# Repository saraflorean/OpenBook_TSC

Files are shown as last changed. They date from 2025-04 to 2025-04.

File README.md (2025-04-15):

# OpenBook_TSC

## Florean Sara-Denisa - 333CD

# Diagrama Block

Diagrama Block

---

# Descrierea modulelor hardware

## Microcontroler – ESP32-C6-WROOM-1-N8

ESP32-C6 este unitatea centrală de procesare responsabilă pentru gestionarea tuturor operațiunilor sistemului, comunicarea cu senzorii și modulele, precum și managementul energiei.

- **Arhitectură:** RISC-V pe 32 de biți  
- **Frecvență ceas:** 160 MHz  
- **Conectivitate wireless:** Wi-Fi 6 la 2.4 GHz, Bluetooth 5.0  

## Management Energetic & Baterie

- **Tip baterie:** Li-Po (Litiu-Polimer)  
- **Capacitate:** 3.7V, 1800mAh  
- **Circuit de încărcare:** MCP73831T  
- **Tensiune de intrare:** 5V prin USB-C  
- **Protecții:** Protecție la supraîncărcare și descărcare profundă  
- **Regulator de tensiune:** Regulator LDO care asigură o alimentare stabilă de 3.3V pentru toate componentele
  
## Afișaj – Ecran E-Paper (E-Ink)

- **Dimensiune:** 7.5 inci  
- **Rezoluție:** 800x480 pixeli  
- **Interfață de comunicare:** SPI  

## Modul Card SD

- **Tip:** MicroSD (Suportă FAT32)  
- **Interfață:** SPI  

## Memorie NOR Flash Externă

- **Capacitate:** 64MB  
- **Interfață:** SPI  

## Senzor de Mediu – BME688

- **Funcții:** Măsoară temperatura, umiditatea, presiunea aerului și nivelurile de gaz  
- **Interfață de comunicare:** I2C  

## Ceas în Timp Real (RTC) – DS3231SN

- **Funcționalitate:** Păstrează ora și data chiar și atunci când sistemul este oprit  
- **Interfață de comunicare:** I2C  

## Conector USB-C & Protecție ESD

- **Funcționalitate:** Asigură alimentarea și transferul de date  
- **Protecție:** Protecție ESD integrată și diodă Schottky pentru protecție la polaritate inversă  

## Butoane & Interacțiune cu Utilizatorul

- **Butoane tactile (push):** Utilizate pentru control manual  

## Interfețe de Comunicație

- **GPIO:** Folosit pentru controlul butoanelor și operațiuni generale I/O  
- **SPI:** Utilizat pentru cardul SD, memoria flash externă și ecranul e-paper  
- **I2C:** Utilizat pentru senzorul de mediu BME688 și modulul RTC DS3231SN  
- **UART:** Utilizat pentru depanare și comunicație serială  
- **Wi-Fi & Bluetooth:** Asigurate de ESP32-C6 pentru conectivitate wireless  

---

## Lista Componentelor folosite

| Componentă | Link | Fișă Tehnică |
|---|---|---|
| MAX17048G+T10 | [Model](https://www.snapeda.com/parts/MAX17048G+T10/Analog+Devices/view-part/?ref=eda) | [Datasheet](https://www.alldatasheet.com/view.jsp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) |
| MCP73831T-5ACI/OT | [Model](https://www.mouser.co.uk/ProductDetail/Microchip-Technology/MCP73831T-5ACI-OT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) | [Datasheet](//efaidnbmnnnibpcajpcglclefindmkaj/https://ww1.microchip.com/downloads/en/DeviceDoc/MCP73831-Family-Data-Sheet-DS20001984H.pdf) |
| USB4110-GF-A  | [Model](https://componentsearchengine.com/part-view/USB4110-GF-A/GCT%20(GLOBAL%20CONNECTOR%20TECHNOLOGY)) | [Datasheet](//efaidnbmnnnibpcajpcglclefindmkaj/https://gct.co/files/drawings/usb4110.pdf) |
| Adafruit | [Model](https://eu.mouser.com/ProductDetail/Adafruit/4208?qs=PzGy0jfpSMtbScLbr0L5dw%3D%3D) | [Datasheet](https://www.arrow.com/en/manufacturers/adafruit-industries/datasheets) |
| CAPACITOR | [Model](https://componentsearchengine.com/part-view/R0402%201%25%20100%20K%20(RC0402FR-07100KL)/YAGEO) | [Datasheet](//efaidnbmnnnibpcajpcglclefindmkaj/https://www.resistor.com/assets/pdf/0402tstd.pdf) |
| CPH3225A | [Model](https://www.snapeda.com/parts/CPH3225A/Seiko+Instruments/view-part/?ref=eda) | [Datasheet](https://octopart.com/datasheet/cph3225a-seiko-25340571) |
| EVQPUJ02K | [Model](https://industry.panasonic.com/global/en/products/control/switch/light-touch/number/evqpuj02k) | [Datasheet](https://www.lcsc.com/datasheet/lcsc_datasheet_2201121800_PANASONIC-EVQPUJ02K_C2936858.pdf) |
| KP-1608SURCK | [Model](https://www.snapeda.com/parts/KP-1608SURCK/Kingbright/view-part/?ref=search&t=LED%200603) | [Datasheet](//efaidnbmnnnibpcajpcglclefindmkaj/https://media.elv.com/file/107153_led_surck1608_data.pdf) |
| USBLC6-2SC6Y | [Model](https://www.snapeda.com/parts/USBLC6-2SC6Y/STMicroelectronics/view-part/?ref=eda) | [Datasheet](https://www.digikey.com/en/htmldatasheets/production/1375342/0/0/1/usblc6-2sc6y) |
| SD0805S020S1R0 | [Model](https://ro.mouser.com/ProductDetail/KYOCERA-AVX/SD0805S020S1R0?qs=jCA%252BPfw4LHbpkAoSnwrdjw%3D%3D) | [Datasheet](https://www.alldatasheet.com/view.jsp?Searchword=SD0805S&sField=2) |
| PGB1010603MR | [Model](https://www.snapeda.com/parts/PGB1010603MR/Littelfuse/view-part/?ref=eda) | [Datasheet](https://www.alldatasheet.com/view.jsp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) |
| BD5229G-TR  | [Model](https://componentsearchengine.com/part-view/BD5229G-TR/ROHM%20Semiconductor) | [Datasheet](https://www.lcsc.com/datasheet/lcsc_datasheet_2201131330_ROHM-Semicon-BD5229G-TR_C962636.pdf) |
| BME680 | [Model](https://www.snapeda.com/parts/BME680/Bosch/view-part/?welcome=home) | [Datasheet](//efaidnbmnnnibpcajpcglclefindmkaj/https://www.bosch-sensortec.com/media/boschsensortec/downloads/datasheets/bst-bme680-ds001.pdf) |
| XC6220A331MR-G | [Model](https://componentsearchengine.com/part-view/XC6220A331MR-G/Torex) | [Datasheet](https://www.alldatasheet.com/view.jsp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) |
| SMD Solder | [Model](https://grabcad.com/library/solder-jumpers-1) | [Datasheet]() |
| BUTTON | [Model](https://industry.panasonic.com/global/en/products/control/switch/light-touch/number/evqpuj02k) | [Datasheet](https://www.lcsc.com/datasheet/lcsc_datasheet_2201121800_PANASONIC-EVQPUJ02K_C2936858.pdf) |
| Bobina | [Model](https://store.comet.srl.ro/Catalogue/Product/43497/) | [Datasheet](https://www.scribd.com/document/814581278/Datasheet-Bobina) |
| PFMF | [Model](https://www.mouser.co.uk/ProductDetail/EPCOS-TDK/B72520T0350K062?qs=dEfas%2FXlABIszF52uu7vrg%3D%3D) | [Datasheet](https://ro.mouser.com/c/ds/circuit-protection/thermistors/resettable-fuses-pptc/?m=Schurter&series=PFMF) |
| DMG2305UX-7 | [Model](https://componentsearchengine.com/part-view/DMG2305UX-7/Diodes%20Incorporated) | [Datasheet](//efaidnbmnnnibpcajpcglclefindmkaj/https://www.mouser.com/datasheet/2/115/DMG2305UX-266242.pdf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) |
| Si1308EDL-T1-GE3 | [Model](https://componentsearchengine.com/part-view/SI1308EDL-T1-GE3/Vishay) | [Datasheet](https://www.alldatasheet.com/view.jsp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) |
| R0402 | [Model](https://componentsearchengine.com/part-view/R0402%201%25%20100%20K%20(RC0402FR-07100KL)/YAGEO) | [Datasheet](//efaidnbmnnnibpcajpcglclefindmkaj/https://www.resistor.com/assets/pdf/0402tstd.pdf) |
| W25Q512JVEIQ | [Model](https://www.snapeda.com/parts/ESP32-C6-WROOM-1-N8/Espressif+Systems/view-part/?ref=eda) | [Datasheet](//efaidnbmnnnibpcajpcglclefindmkaj/https://www.mouser.com/datasheet/2/949/W25Q512JV_SPI_RevB_06252019_KMS-2487502.pdf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) |
| ESP32-C6-WROOM-1-N8 | [Model](https://www.snapeda.com/parts/ESP32-C6-WROOM-1-N8/Espressif+Systems/view-part/?ref=eda) | [Datasheet](//efaidnbmnnnibpcajpcglclefindmkaj/https://www.mouser.com/catalog/specsheets/Espressif_ESP32_C6_WROOM_1%20_Datasheet_V0.1_PRELIMINARY_en.pdf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) |
| DS3231SN# | [Model](https://www.snapeda.com/parts/DS3231SN%23/Analog+Devices/view-part/?ref=eda) | [Datasheet](https://www.alldatasheet.com/view.jsp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) |

---

## Mapare Pini – ESP32-C6

| Denumire | Pin GPIO | Utilizare |
|---|---|---|
| Buton Reset | EN | Resetare ESP32-C6 |
| INT_RTC | IO0 | Semnal de întrerupere de la RTC (DS3231)|
| 32KHZ | IO1 | Semnal de ceas 32 kHz |
| MISO (SPI) | IO2 | Recepție date SPI |
| EPD BUSY | IO3 | Indicator stare E-Paper |
| SS_SD | IO4 | Chip Select pentru card SD (SPI) |
| EPD DC | IO5 | Data/Command pentru E-Paper |
| SCK (SPI) | IO6 | Clock pentru SPI |
| MOSI (SPI) | IO7 | Transmitere date SPI |
| Buton Boot | IO9 | Intrare în bootloader |
| 3V3 | 3V3 | Alimentare 3.3V |
| EPD_CS | IO10 | Selectare SPI pentru E-Paper |
| FLASH_CS | IO11 | Selectare SPI pentru NOR Flash |
| USB_D- | IO12 | Linie diferențială USB (minus) |
| USB_D+ | IO13 | Linie diferențială USB (plus) |
| Buton Change | IO15 | Schimbare mod operare |
| TX (UART) | TXD0/GPIO16 | Transmitere date UART |
| RX (UART) | RXD0/GPIO17 | Recepție date UART |
| RTC_RST | IO18 | Reset extern/semnal RTC |
| I2C_PW | IO19 | Linie de alimentare / enable pentru I2C |
| EPD_3V3_C | IO20 | Linie de alimentare 3.3V pentru E-Paper |
| SDA (I2C) | IO21 | Linie de date I2C |
| SCL (I2C) | IO22 | Linie de ceas I2C |
| EPD RST | IO23 | Resetare E-Paper |

---

## Informații adiționale

**Erori SMD-Hole Board Outline Clearance la Mufa USB:**  
  - Am identificat două erori de tip **SMD-Hole Board Outline Clearance** asociate mufei USB. Conform informațiilor tehnice primite, aceste erori au fost **acceptate**.

**Redimensionarea și amplasarea componentelor:**
  - Dimensiunile unor componente au fost **ajustate** pentru a rezolva incompatibilitățile detectate de verificatorul de design.
  - Condensatori de decuplare de 100nF au fost **amplasați aproape de pinii de alimentare** ai circuitelor integrate (IC), în conformitate cu practicile standard de proiectare pentru reducerea zgomotului electric.
  - Componentele au fost amplasate respectând pe cât de mult posibil **specifcațiile proiectului** asigurând compatibilitatea dintre carcasa oferită și dimensiunile PCB-ului.
  - **TP-urile** au fost amplasate diferit față de specificațiile oferite, pentru a facilita o rutare eficientă. Poziția lor fiind determinată de apropierea de piesele conectate.

 **Rutare și planuri de masă**
 - **Traseele de alimentare** au fost rutate **doar pe stratul superior**, ceea ce a necesitat utilizarea a aproximativ 100 de vias-uri pentru a permite rutarea semnalelor pe stratul inferior.
 - **Planul de masă** (GND) a fost adăugat după finalizarea rutării, aplicat atât pe stratul superior, cât și pe cel inferior, pentru a asigura o împământare cu impedanță redusă și pentru a diminua interferențele electromagnetice (EMI).
 - Am realizat **via stitching** în regiunile unde planurile de masă de pe stratul superior și inferior se suprapuneau, pentru a asigura o conexiune electrică solidă între acestea.

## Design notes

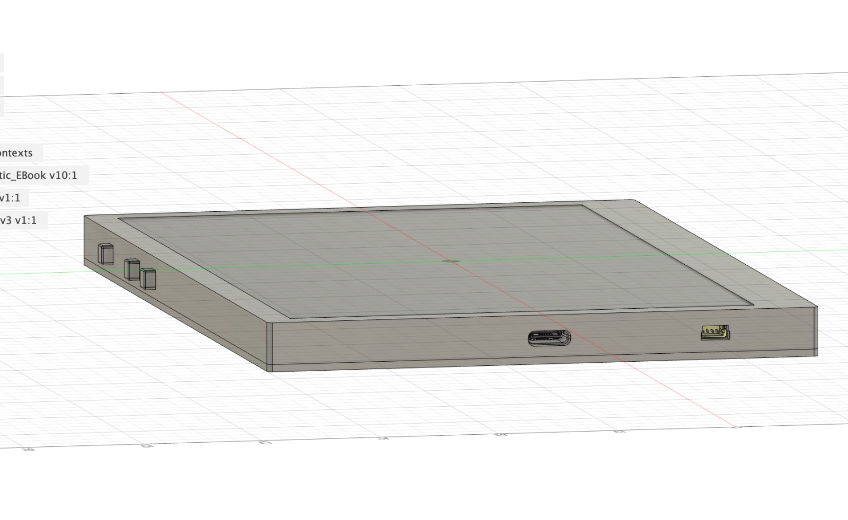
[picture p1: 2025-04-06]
Images/OpenBook.jpeg

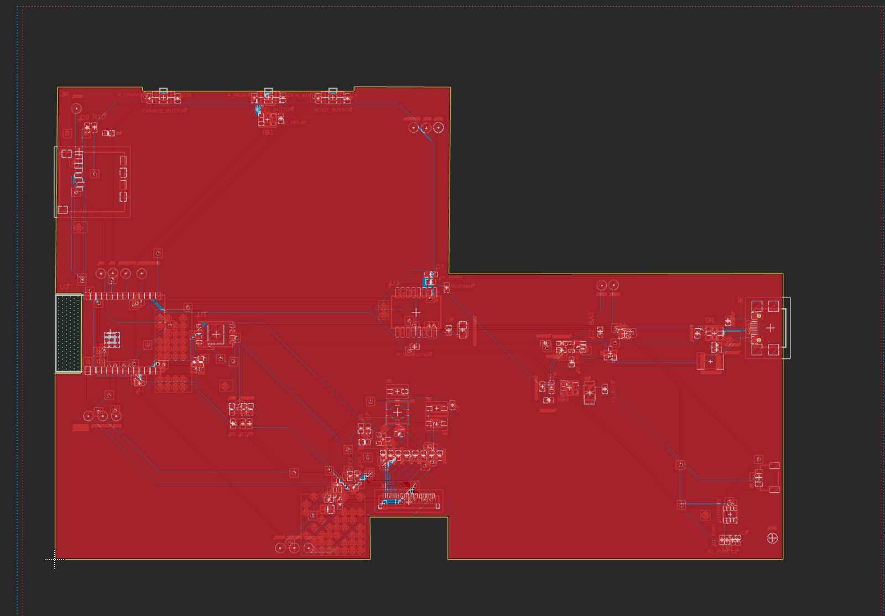
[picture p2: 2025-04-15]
Images/Top_Routing.jpeg

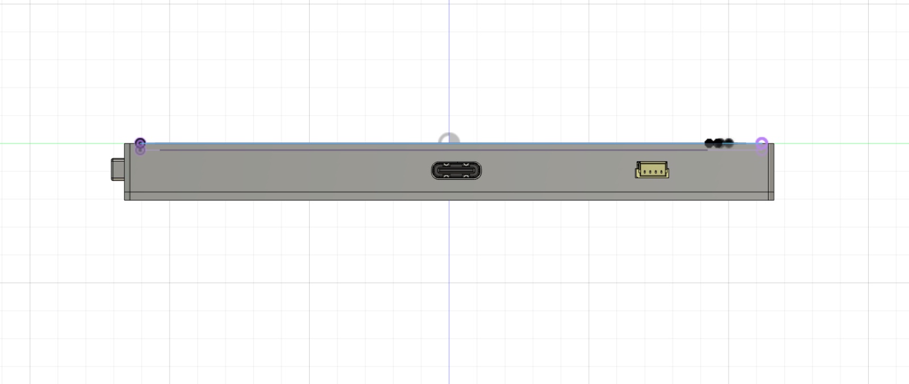
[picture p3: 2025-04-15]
Images/Extern_plug_ins.jpeg

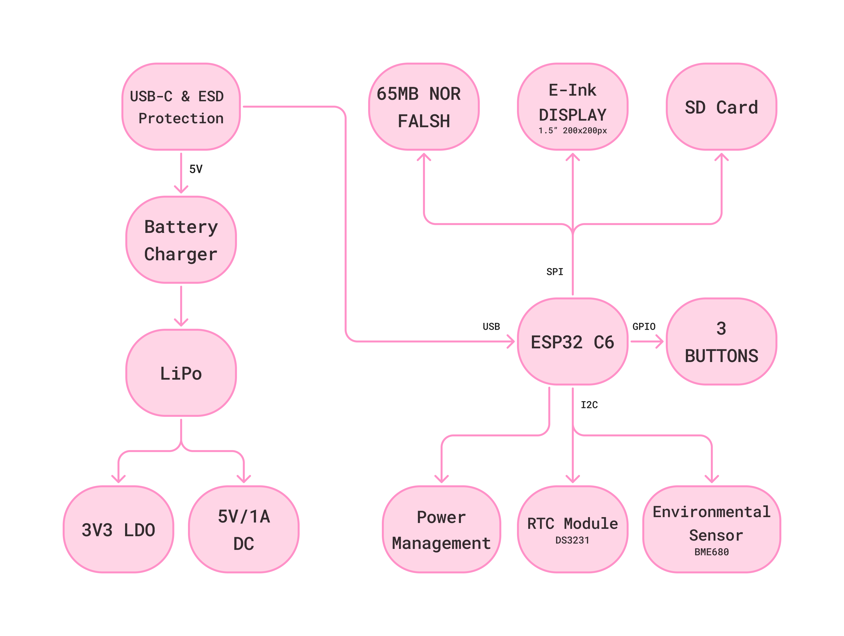
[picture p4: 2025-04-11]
Images/Diagrama Block.png

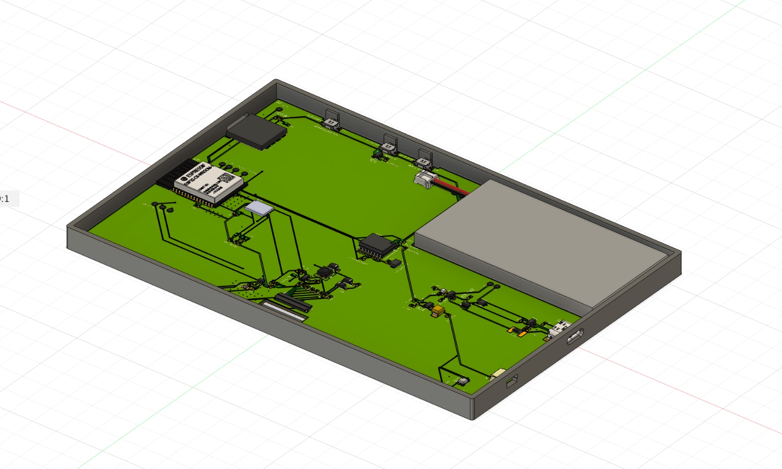
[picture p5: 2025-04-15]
Images/3D_view.jpeg

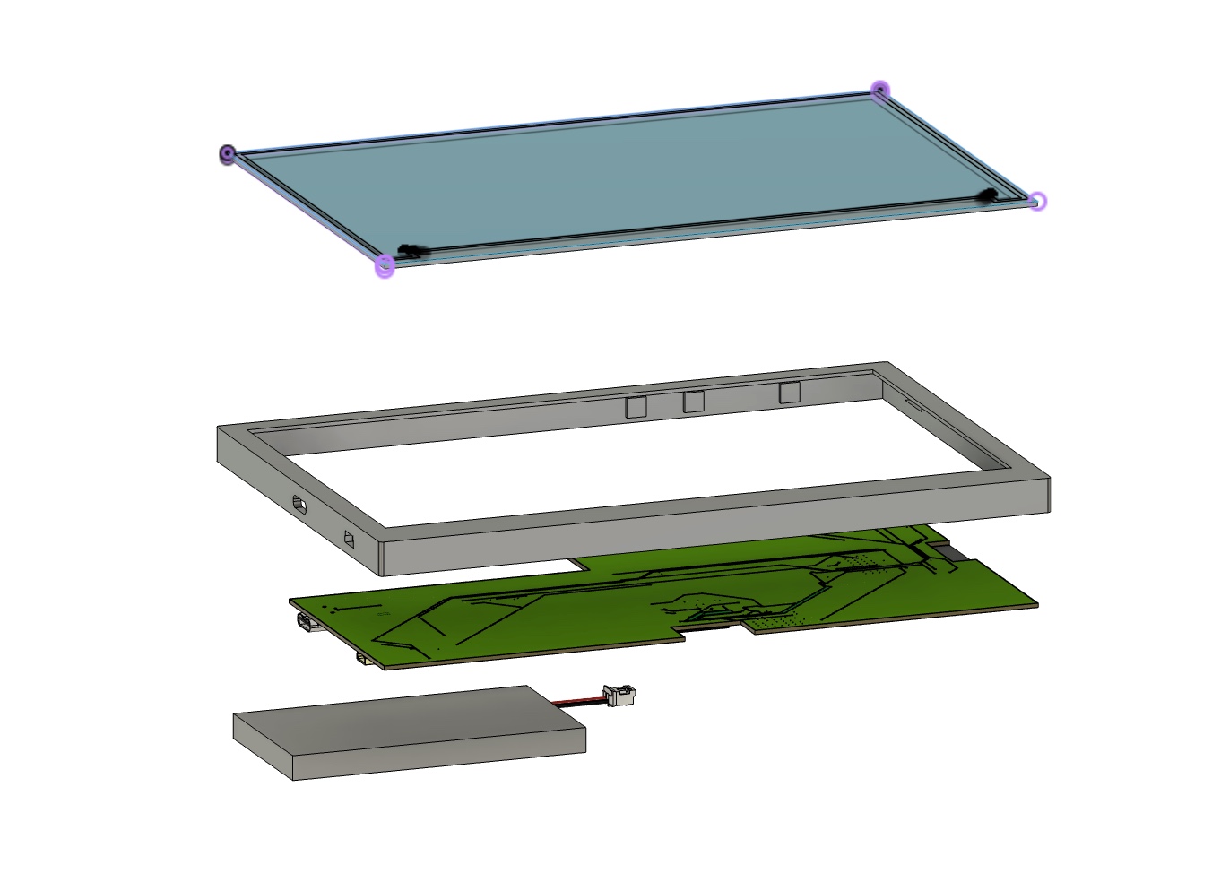
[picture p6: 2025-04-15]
Images/Exploded_View.jpeg

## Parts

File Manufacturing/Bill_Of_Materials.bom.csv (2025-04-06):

Qty | Value | Device | Package | Parts | Description | ARROW_PART_NUMBER | ARROW_PRICE-STOCK | AVAILABILITY | CENTROID_NOT_SPECIFIED | CHECK_PRICES | COPYRIGHT | DATASHEET | DESCRIPTION | DIGIKEY_DESCRIPTION | DIGIKEY_PART_NUMBER | HEIGHT | LEAD_FREE | MANUFACTURER_NAME | MANUFACTURER_PART_NUMBER | MF | MFR_NAME | MOUSER_PART_NUMBER | MOUSER_PRICE-STOCK | MOUSER_TESTING_PART_NUMBER | MOUSER_TESTING_PRICE-STOCK | MP | MPN | PACKAGE | POPULARITY | PREFIX | PRICE | PROD_ID | PURCHASE-URL | ROHS | SNAPEDA_LINK | SPICEMODEL | SPICEPREFIX | TEMPERATURE_RANGE_HIGH | TEMPERATURE_RANGE_LOW | TP_SIGNAL_NAME | VALUE | LSCS Part number
1 |  | ADAFRUIT_LEDCHIP-LED0603 | ADAFRUIT_CHIP-LED0603 | CHG_LED | LED
1 |  | SJ | SJ | SJ1 | SMD solder JUMPER |  |  |  |  |  |  |  |  |  |  |  |  |  |  |  |  |  |  |  |  |  |  |  | 3
1 | 0.1uF/50V | EAGLE-LTSPICE_CC0402 | EAGLE-LTSPICE_C0402 | EPD_C5 | CAPACITOR, European symbol |  |  |  |  |  |  |  |  |  |  |  |  |  |  |  |  |  |  |  |  |  |  |  |  |  |  |  |  |  |  | NONE | C
1 | 0.47 | ESP32_WROVER_EAGLE-LTSPICE_RR0402 | ESP32_WROVER_EAGLE-LTSPICE_R0402 | R3 | RESISTOR, European symbol |  |  |  |  |  |  |  |  |  |  |  |  |  |  |  |  |  |  |  |  |  |  |  |  |  |  |  |  |  |  | NONE | R
1 | 100K | ESP32_WROVER_EAGLE-LTSPICE_RR0402 | ESP32_WROVER_EAGLE-LTSPICE_R0402 | R1_PWRUSB | RESISTOR, European symbol |  |  |  |  |  |  |  |  |  |  |  |  |  |  |  |  |  |  |  |  |  |  |  |  |  |  |  |  |  |  | NONE | R
8 | 100nF | EAGLE-LTSPICE_CC0402 | EAGLE-LTSPICE_C0402 | C1, C2, C4_USB, C6, C8, C9, C10, C_DELAY | CAPACITOR, European symbol |  |  |  |  |  |  |  |  |  |  |  |  |  |  |  |  |  |  |  |  |  |  |  |  |  |  |  |  |  |  | NONE | C
1 | 100uF TANT | RCL_CPOL-EUCT3528 | RCL_CT3528 | C3 | POLARIZED CAPACITOR, European symbol |  |  |  |  |  |  |  |  |  |  |  |  |  |  |  |  |  |  |  |  |  |  |  | 0 |  |  |  |  |  |  |  | C
16 | 10K | ESP32_WROVER_EAGLE-LTSPICE_RR0402 | ESP32_WROVER_EAGLE-LTSPICE_R0402 | R1, R1_PINH, R1_PINH1, R2-PINH1, R2_PINH, R4, R5, R6, R7, R8, R9, R10, R_BOOT, R_CHANGE, R_CL1, R_RESET | RESISTOR, European symbol |  |  |  |  |  |  |  |  |  |  |  |  |  |  |  |  |  |  |  |  |  |  |  |  |  |  |  |  |  |  | NONE | R
1 | 10uF | EAGLE-LTSPICE_CC0402 | EAGLE-LTSPICE_C0402 | C7 | CAPACITOR, European symbol |  |  |  |  |  |  |  |  |  |  |  |  |  |  |  |  |  |  |  |  |  |  |  |  |  |  |  |  |  |  | NONE | C
1 | 112A-TAAR-R03_ATTEND | 112A-TAAR-R03_ATTEND | 112ATAARR03ATTEND | J4 | Micro SD Card Socket, Push-Push Type, Top Mount, SMT, H=1.83mm, 10u |  |  |  |  |  |  |  | Micro SD Card Socket | Push-Push Type | Top Mount | SMT | H=1.83mm | 10u |  |  | 1.9mm |  | ATTEND | 112A-TAAR-R03 ATTEND
1 | 15 | ESP32_WROVER_EAGLE-LTSPICE_RR0402 | ESP32_WROVER_EAGLE-LTSPICE_R0402 | R_CAPACITOR | RESISTOR, European symbol |  |  |  |  |  |  |  |  |  |  |  |  |  |  |  |  |  |  |  |  |  |  |  |  |  |  |  |  |  |  | NONE | R
1 | 1uF | EAGLE-LTSPICE_CC0402 | EAGLE-LTSPICE_C0402 | C5 | CAPACITOR, European symbol |  |  |  |  |  |  |  |  |  |  |  |  |  |  |  |  |  |  |  |  |  |  |  |  |  |  |  |  |  |  | NONE | C
9 | 1uF/50V | EAGLE-LTSPICE_CC0402 | EAGLE-LTSPICE_C0402 | EPD_C1, EPD_C2, EPD_C6, EPD_C7, EPD_C8, EPD_C9, EPD_C10, EPD_C11, EPD_C12 | CAPACITOR, European symbol |  |  |  |  |  |  |  |  |  |  |  |  |  |  |  |  |  |  |  |  |  |  |  |  |  |  |  |  |  |  | NONE | C
1 | 2.2 | ESP32_WROVER_EAGLE-LTSPICE_RR0402 | ESP32_WROVER_EAGLE-LTSPICE_R0402 | R2 | RESISTOR, European symbol |  |  |  |  |  |  |  |  |  |  |  |  |  |  |  |  |  |  |  |  |  |  |  |  |  |  |  |  |  |  | NONE | R
1 | 200 | ESP32_WROVER_EAGLE-LTSPICE_RR0402 | ESP32_WROVER_EAGLE-LTSPICE_R0402 | R1_BAT | RESISTOR, European symbol |  |  |  |  |  |  |  |  |  |  |  |  |  |  |  |  |  |  |  |  |  |  |  |  |  |  |  |  |  |  | NONE | R
2 | 20V/4.2A/52mΩ/1.4W | ESP32_WROVER_SPARKFUN-DISCRETESEMI_MOSFET_PCH-DMG2305UX-7 | ESP32_WROVER_SPARKFUN-DISCRETESEMI_SOT23-3 | Q1, Q2 | P-channel MOSFETs |  |  |  |  |  |  |  |  |  |  |  |  |  |  |  |  |  |  |  |  |  |  |  |  |  |  | TRAN-14388 |  |  |  |  |  |  |  |  | 20V/4.2A/52mΩ/1.4W
1 | 2K | ESP32_WROVER_EAGLE-LTSPICE_RR0402 | ESP32_WROVER_EAGLE-LTSPICE_R0402 | R2_BAT | RESISTOR, European symbol |  |  |  |  |  |  |  |  |  |  |  |  |  |  |  |  |  |  |  |  |  |  |  |  |  |  |  |  |  |  | NONE | R
4 | 4.7uF | EAGLE-LTSPICE_CC0402 | EAGLE-LTSPICE_C0402 | C1_BAT, C1_BAT1, C2_BAT, C5_USB | CAPACITOR, European symbol |  |  |  |  |  |  |  |  |  |  |  |  |  |  |  |  |  |  |  |  |  |  |  |  |  |  |  |  |  |  | NONE | C
1 | 4.7uF | ESP32_WROVER_EAGLE-LTSPICE_CC0402 | EAGLE-LTSPICE_C0402 | C1_BAT2 | CAPACITOR, European symbol |  |  |  |  |  |  |  |  |  |  |  |  |  |  |  |  |  |  |  |  |  |  |  |  |  |  |  |  |  |  | NONE | C
1 | 4.7uF/25V | EAGLE-LTSPICE_CC0402 | EAGLE-LTSPICE_C0402 | C4 | CAPACITOR, European symbol |  |  |  |  |  |  |  |  |  |  |  |  |  |  |  |  |  |  |  |  |  |  |  |  |  |  |  |  |  |  | NONE | C
2 | 5k1 | ESP32_WROVER_EAGLE-LTSPICE_RR0402 | ESP32_WROVER_EAGLE-LTSPICE_R0402 | R2-USB, R2-USB1 | RESISTOR, European symbol |  |  |  |  |  |  |  |  |  |  |  |  |  |  |  |  |  |  |  |  |  |  |  |  |  |  |  |  |  |  | NONE | R
1 | 68uH | 744043680IND_4828-WE-TPC_WRE | IND_4828-WE-TPC_WRE | L1 |  |  |  |  |  |  | Copyright (C) 2024 Ultra Librarian. All rights reserved. |  |  |  |  |  |  |  | 744043680 |  | Wurth Electronics
1 | BD5229G-TR | BD5229G-TR | SOT95P280X125-5N | IC1 | Voltage Detector with Adjustable Delay Time: CMOS processes are utilized to develop high precision, low current consumption CMOS reset ICs that allow arbitrary setting of the delay time. The extensive lineup includes both Nch Open Drain and CMOS output types in a wide range of detection voltages (from 2.3V to 6.0V, in 0.1V steps), enabling selection of the ideal solution based on customer requirements. In addition, the entire series is of course both lead-free and RoHS-compliant. |  |  |  |  |  |  |  | Voltage Detector with Adjustable Delay Time: CMOS processes are utilized to develop high precision | low current consumption CMOS reset ICs that allow arbitrary setting of the delay time. The extensive lineup includes both Nch Open Drain and CMOS output types in a wide range of detection voltages (from 2.3V to 6.0V | in 0.1V steps) | enabling selection of the ideal solution based on customer requirements. In addition | the entire series is of course both lead-free and RoHS-compliant. |  |  | 1.25mm |  | ROHM Semiconductor | BD5229G-TR |  |  | 755-BD5229G-TR | https://www.mouser.co.uk/ProductDetail/ROHM-Semiconductor/BD5229G-TR?qs=4kLU8WoGk0vvnhrrYwdszw%3D%3D
3 | BUTTON_CUSYOMV1 | BUTTON_CUSYOMV1 | MYBUTTON | BOOT_BUTTON, CHANGE_BUTTON, RESET_BUTTON
1 | CPH3225A | CPH3225A | CAPCP3225X100N | C10_SUPERCAP | Cap 0.011F 3.3V 1210 Flat Check availability |  |  | Not in stock |  | https://www.snapeda.com/parts/CPH3225A/Seiko+Instruments/view-part/?ref=eda |  |  | 11 mF (EDLC) Supercapacitor 3.3 V 1210 (3225 Metric) - - |  |  |  |  |  |  | Seiko Instruments |  |  |  |  |  | CPH3225A |  | 1210 Seiko |  |  | None |  | https://www.snapeda.com/api/url_track_click_mouser/?unipart_id=562593&manufacturer=Seiko Instruments&part_name=CPH3225A&search_term=None |  | https://www.snapeda.com/parts/CPH3225A/Seiko+Instruments/view-part/?ref=snap
1 | DS3231SN# | DS3231SN# | SOIC127P1032X265-16N | U3 | Real Time Clock Serial 16-Pin SOIC W T/R Check availability |  |  | In Stock |  | https://www.snapeda.com/parts/DS3231SN%23/Analog+Devices/view-part/?ref=eda |  |  | Extremely Accurate I²C-Integrated RTC/TCXO/Crystal |  |  |  |  |  |  | Analog Devices |  |  |  |  |  | DS3231SN# |  | SOIC-16 Maxim |  |  | None |  | https://www.snapeda.com/api/url_track_click_mouser/?unipart_id=99048&manufacturer=Analog Devices&part_name=DS3231SN#&search_term=None |  | https://www.snapeda.com/parts/DS3231SN%23/Analog+Devices/view-part/?ref=snap
1 | ESP32-C6-WROOM-1-N8 | ESP32-C6-WROOM-1-N8 | XCVR_ESP32-C6-WROOM-1-N8 | U2 | Check availability |  |  | In Stock |  | https://www.snapeda.com/parts/ESP32-C6-WROOM-1-N8/Espressif+Systems/view-part/?ref=eda |  |  | Multiprotocol Modules ESP32-C6 module | Wi-Fi 6 in 2.4 GHz band | Bluetooth 5 | Zigbee 3.0 and Thread. ESP34-WROOM Compatible - ENGINEERING SAMPLE |  |  |  |  |  |  | Espressif Systems |  |  |  |  |  | ESP32-C6-WROOM-1-N8 |  | None |  |  | None |  |  |  | https://www.snapeda.com/parts/ESP32-C6-WROOM-1-N8/Espressif+Systems/view-part/?ref=snap
1 | ESP32C6_VARISTORCN1812 | ESP32C6_VARISTORCN1812 | ESP32C6_VARISTOR_CT/CN1812 | PFMF.050.1 | VARISTOR |  |  |  |  |  |  |  |  |  |  |  |  |  |  |  |  |  |  |  |  |  |  |  | 0
2 | ESP32_WROVER_AVX---SD0805S020S1R0_AVX_SD0805S020S1R0_0_0AVX_SD0805S020S1R0_0_0 | ESP32_WROVER_AVX---SD0805S020S1R0_AVX_SD0805S020S1R0_0_0AVX_SD0805S020S1R0_0_0 | ESP32_WROVER_AVX---SD0805S020S1R0_AVX_SD0805S020S1R0_0 | D2, D7 | Schottky Barrier Rectifier Diode |  |  |  | No |  |  | http://datasheets.avx.com/schottky.pdf |  | DIODE SCHOTTKY 20V 1A 0805 | 478-7800-1-ND |  | yes |  |  | AVX |  | 581-SD0805S020S1R0 |  |  |  |  |  | 0805 (2012 metric) |  | D |  |  |  | yes |  |  |  | +125°C | -55°C
1 | ESP32_WROVER_BME680_BME680 | ESP32_WROVER_BME680_BME680 | ESP32_WROVER_BME680_PSON80P300X300X100-8N | SENSOR2 | Integrated Environmental Unit |  |  | Unavailable |  |  |  |  | Integrated Environmental Unit |  |  |  |  |  |  | Bosch Sensortec |  |  |  |  |  | BME680 |  | LGA-8 Bosch Tools |  |  | None
1 | ESP32_WROVER_SPARKFUN-IC-POWER_MCP73831 | ESP32_WROVER_SPARKFUN-IC-POWER_MCP73831 | ESP32_WROVER_SPARKFUN-IC-POWER_SOT23-5 | MCP73831 | MCP73831T Li-Ion, Li-Pol Controller |  |  |  |  |  |  |  |  |  |  |  |  |  |  |  |  |  |  |  |  |  |  |  |  |  |  | IC-09995
1 | FH34SRJ-24S-0.5SH_99_ | FH34SRJ-24S-0.5SH_99_ | FH34SRJ24S05SH99 | J1 | (0.50mm) Surface Mount, Right Angle |  |  |  |  |  |  |  | 24 Position FFC | FPC Connector Contacts | (0.50mm) Surface Mount | Right Angle |  |  | 1.1mm |  | Hirose | FH34SRJ-24S-0.5SH(99) |  |  | 798-FH34SRJ24S05SH99 | https://www.mouser.co.uk/ProductDetail/Hirose-Connector/FH34SRJ-24S-0.5SH99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
1 | MAX17048G+T10 | MAX17048G+T10 | SON50P200X200X80-9N | U4 | Check availability |  |  | In Stock |  | https://www.snapeda.com/parts/MAX17048G+T10/Analog+Devices/view-part/?ref=eda |  |  | 3µA 1-Cell/2-Cell Fuel Gauge with ModelGauge |  |  |  |  |  |  | Analog Devices |  |  |  |  |  | MAX17048G+T10 |  | TDFN-8 Maxim |  |  | None |  | https://www.snapeda.com/api/url_track_click_mouser/?unipart_id=329239&manufacturer=Analog Devices&part_name=MAX17048G+T10&search_term=None |  | https://www.snapeda.com/parts/MAX17048G+T10/Analog+Devices/view-part/?ref=snap
3 | MBR0530 | MBR0530 | SOD3716X135N | D3, D4, D5 | ON SEMICONDUCTOR - MBR0530 - DIODE, SCHOTTKY, 0.5A, 30V, SOD-123 |  |  | In Stock |  | https://www.snapeda.com/parts/MBR0530/Onsemi/view-part/?ref=eda |  |  | Diode Schottky 30 V 500mA Surface Mount SOD-123 |  |  |  |  |  |  | ON Semiconductor |  |  |  |  |  | MBR0530 |  | SOD-123-2 ON Semiconductor |  |  | None |  | https://www.snapeda.com/api/url_track_click_mouser/?unipart_id=179458&manufacturer=ON Semiconductor&part_name=MBR0530&search_term=None |  | https://www.snapeda.com/parts/MBR0530/Onsemi/view-part/?ref=snap
6 | PGB1010603MR | PGB1010603MR | DIOC1608X36N | D6, D8, D9, D10, D11, D12 | Check availability |  |  | In Stock |  | https://www.snapeda.com/parts/PGB1010603MR/Littelfuse/view-part/?ref=eda |  |  | 150V (Typ) Clamp - Ipp Tvs Diode Surface Mount 0603 (1608 Metric) |  |  |  |  |  |  | Littelfuse Inc. |  |  |  |  |  | PGB1010603MR |  | 0603 Littelfuse Inc. |  |  | None |  | https://www.snapeda.com/api/url_track_click_mouser/?unipart_id=5659453&manufacturer=Littelfuse Inc.&part_name=PGB1010603MR&search_term=None |  | https://www.snapeda.com/parts/PGB1010603MR/Littelfuse/view-part/?ref=snap
1 | QWIIC_RIGHT_ANGLE | QWIIC_CONNECTORJS-1MM | JST04_1MM_RA | J3 | SparkFun I2C Standard Qwiic Connector |  |  |  |  |  |  |  |  |  |  |  |  |  |  |  |  |  |  |  |  |  |  |  |  |  |  | CONN-13694 |  |  |  |  |  |  |  |  | QWIIC_RIGHT_ANGLE
1 | SAMACSYS_PARTS_USB4110-GF-A | SAMACSYS_PARTS_USB4110-GF-A | SAMACSYS_PARTS_USB4110GFA | J2 | CONN USB 2.0 TYPE-C R/A SMT |  |  |  |  |  |  |  | CONN USB 2.0 TYPE-C R/A SMT |  |  | 3.26mm |  | GCT (GLOBAL CONNECTOR TECHNOLOGY) | USB4110-GF-A |  |  | 640-USB4110-GF-A | https://www.mouser.co.uk/ProductDetail/GCT/USB4110-GF-A?qs=KUoIvG%2F9IlYiZvIXQjyJeA%3D%3D
1 | SI1308EDL-T1-GE3 | SI1308EDL-T1-GE3 | SOT65P210X110-3N | Q3 | MOSFET N-Ch 30V 1.5A TrenchFET SC70 Vishay Si1308EDL-T1-GE3 N-channel MOSFET Transistor, 1.5 A, 30 V, 3-Pin SC-70 |  |  | In Stock |  | https://www.snapeda.com/parts/SI1308EDL-T1-GE3/Vishay+Siliconix/view-part/?ref=eda |  |  | Si1308EDL-T1-GE3 N-channel MOSFET Transistor | 1.5 A | 30 V | 3-Pin SC-70 | Siliconix / Vishay SI1308EDL-T1-GE3 |  |  |  |  |  |  | Vishay Siliconix |  |  |  |  |  | SI1308EDL-T1-GE3 |  | SOT-323 Vishay Semiconductor |  |  | None |  | https://www.snapeda.com/api/url_track_click_mouser/?unipart_id=274603&manufacturer=Vishay Siliconix&part_name=SI1308EDL-T1-GE3&search_term=None |  | https://www.snapeda.com/parts/SI1308EDL-T1-GE3/Vishay+Siliconix/view-part/?ref=snap
17 | TPTP20R | TPTP20R | TP20R | TP1, TP2, TP3, TP4, TP5, TP6, TP7, TP8, TP9, TP10, TP11, TP12, TP13, TP14, TP15, TP16, TP17 | Test pad |  |  |  |  |  |  |  |  |  |  |  |  |  |  |  |  |  |  |  |  |  |  |  | 2
1 | USBLC6-2SC6Y | USBLC6-2SC6Y | SOT95P280X145-6N | D1 | Low Cap. ESD Protection Auto SOT-23-6 STMicroelectronics USBLC6-2SC6Y, Dual Uni-Directional TVS Diode Array, 6-Pin SOT-23 |  |  | In Stock |  | https://www.snapeda.com/parts/USBLC6-2SC6Y/STMicroelectronics/view-part/?ref=eda |  |  | 17V Clamp 5A (8/20µs) Ipp Tvs Diode Surface Mount SOT-23-6 |  |  |  |  |  |  | STMicroelectronics |  |  |  |  |  | USBLC6-2SC6Y |  | SOT-23-6 STMicroelectronics |  |  | None |  |  |  | https://www.snapeda.com/parts/USBLC6-2SC6Y/STMicroelectronics/view-part/?ref=snap
1 | W25Q512JVEIQ | W25Q512JVEIQ | SON127P600X800X80-9N | U1 | Check availability |  |  | In Stock |  | https://www.snapeda.com/parts/W25Q512JVEIQ/Winbond+Electronics/view-part/?ref=eda |  |  | FLASH - NOR Memory IC 512Mb (64M x 8) SPI - Quad I/O 133 MHz 8-WSON (8x6) |  |  |  |  |  |  | Winbond Electronics |  |  |  |  |  | W25Q512JVEIQ |  | Package |  |  | None |  |  |  | https://www.snapeda.com/parts/W25Q512JVEIQ/Winbond+Electronics/view-part/?ref=snap
1 | XC6220A331MR-G | XC6220A331MR-G | SOT95P280X120-5N | IC4 | LDO Voltage Regulators |  |  |  |  |  |  |  | LDO Voltage Regulators |  |  | 1.2mm |  | Torex | XC6220A331MR-G |  |  | 865-XC6220A331MR-G | https://www.mouser.co.uk/ProductDetail/Torex-Semiconductor/XC6220A331MR-G?qs=AsjdqWjXhJ8ZSWznL1J0gg%3D%3D

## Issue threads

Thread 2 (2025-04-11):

Erori PCB

florian-ariasu, 2025-04-11:
**Descriere:**

1. Ai 2 erori in urma rutarii.
2. Iti lipseste un custom rule, si anume cel de 0.15mm.

**Imagini sugestive:**
<h4>

> Pentru primul punct:
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
<h4>

> Pentru al doilea punct:
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

**Solutie:**
> Adaugi a 2-a regula de copper width, refaci rutarea si modifici dimensiunea pad-urilor(maresti putin lungimea si latimea de la edit footprint); verifici daca mai apar erori noi de overlap; pentru acelea doar muti firele astfel incat sa ocoleasca componentele.

saraflorean, 2025-04-11:
Dimensiunea firelor a fost setată standard la 0.15mm din General Rules, iar pentru traseele de putere la 0.3mm.

Closed 2025-04-11.

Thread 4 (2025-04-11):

Greseala Masuratori PCB

florian-ariasu, 2025-04-11:
**Descriere:**

- Ai masurat gresit la realizarea PCB-ului. Se masoara 15.30mm de la linia de sus a conturului.
- De asemenea, se poate observa ca spatiul este mult prea mic intre cele 2 componente: J4 si U2.

**Imagine sugestiva:**

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

**Solutie:**

Rulezi `Unroute All`, muti componentele, rutezi din nou.

Closed 2025-04-11.

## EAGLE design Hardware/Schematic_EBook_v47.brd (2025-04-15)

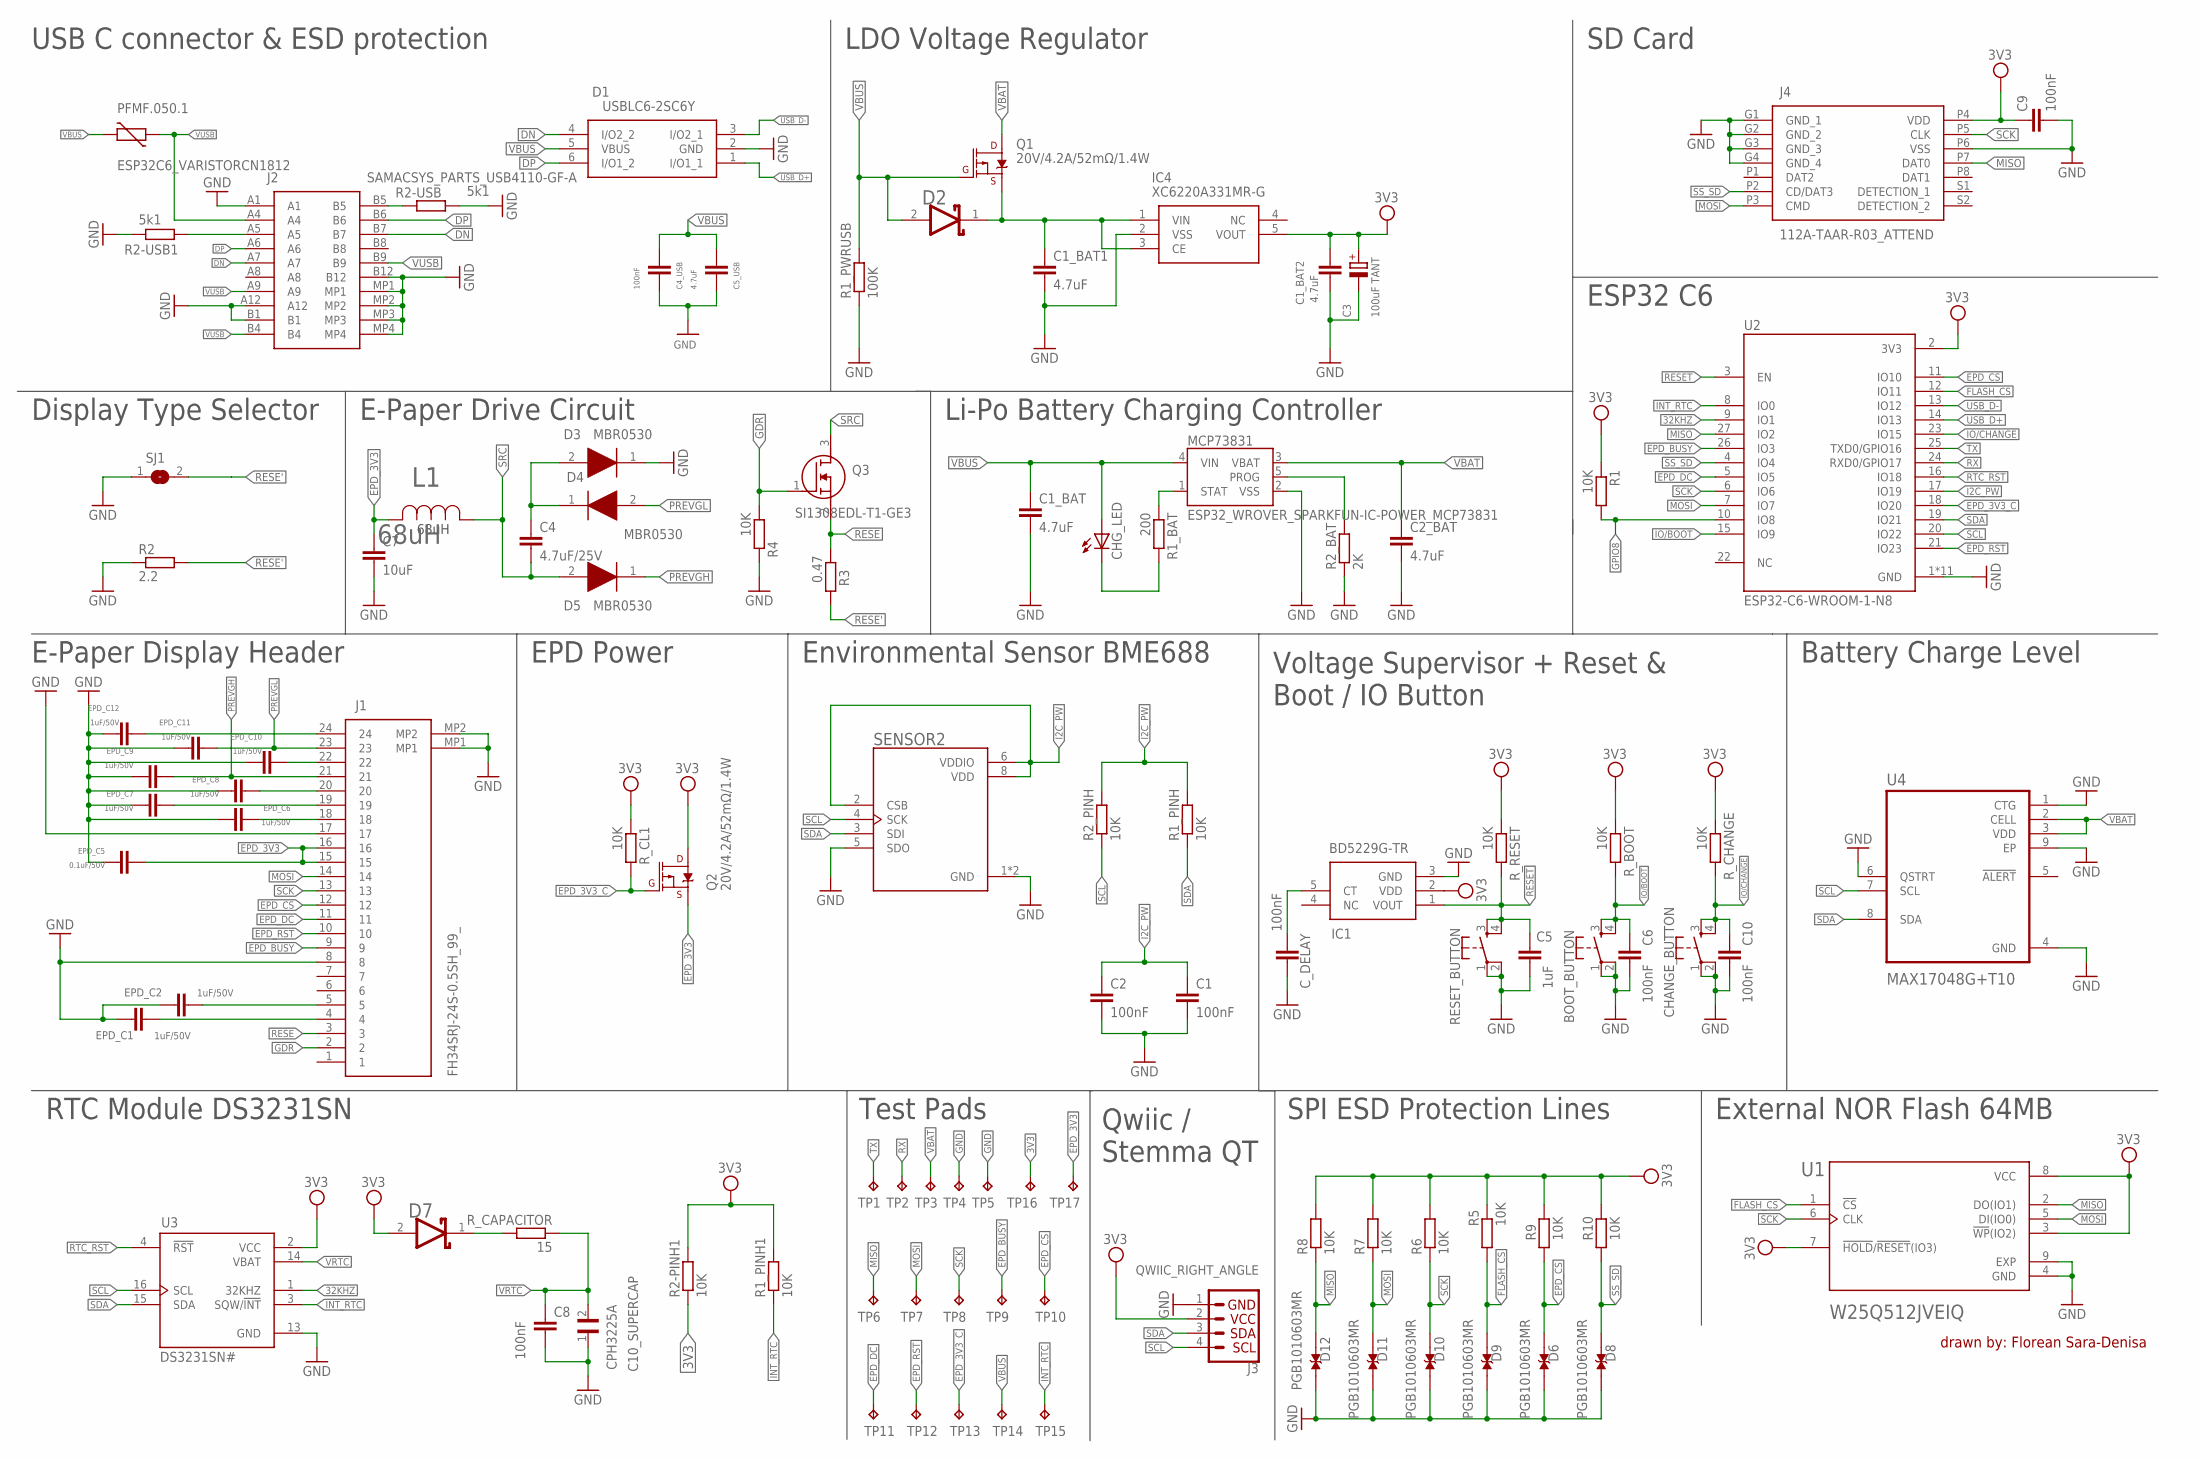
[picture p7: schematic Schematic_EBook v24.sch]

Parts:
BOOT_BUTTON: BUTTON_CUSYOMV1; MYBUTTON
C1, C2, C4_USB, C6, C8, C9, C10: 100nF; EAGLE-LTSPICE_C0402
C1_BAT, C1_BAT1, C1_BAT2, C2_BAT, C5_USB: 4.7uF; EAGLE-LTSPICE_C0402
C3: 100uF TANT; RCL_CT3528
C4: 4.7uF/25V; EAGLE-LTSPICE_C0402
C5: 1uF; EAGLE-LTSPICE_C0402
C7: 10uF; EAGLE-LTSPICE_C0402
C10_SUPERCAP: CPH3225A; CAPCP3225X100N
CHANGE_BUTTON: BUTTON_CUSYOMV1; MYBUTTON
CHG_LED: &; ADAFRUIT_CHIP-LED0603
C_DELAY: 100nF; EAGLE-LTSPICE_C0402
D1: USBLC6-2SC6Y; SOT95P280X145-6N
D2, D7: ESP32_WROVER_AVX---SD0805S020S1R0_AVX_SD0805S020S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; ESP32_WROVER_AVX---SD0805S020S1R0_AVX_SD0805S020S1R0_0
D3, D4, D5: MBR0530; SOD3716X135N
D6, D8, D9, D10, D11, D12: PGB1010603MR; DIOC1608X36N
EPD_C1, EPD_C2, EPD_C6, EPD_C7, EPD_C8, EPD_C9, EPD_C10, EPD_C11, EPD_C12: 1uF/50V; EAGLE-LTSPICE_C0402
EPD_C5: 0.1uF/50V; EAGLE-LTSPICE_C0402
IC1: BD5229G-TR; SOT95P280X125-5N
IC4: XC6220A331MR-G; SOT95P280X120-5N
J1: FH34SRJ-24S-0.5SH_99_; FH34SRJ24S05SH99
J2: SAMACSYS_PARTS_USB4110-GF-A; SAMACSYS_PARTS_USB4110GFA
J3: QWIIC_RIGHT_ANGLE; JST04_1MM_RA
J4: 112A-TAAR-R03_ATTEND; 112ATAARR03ATTEND
L1: 68uH; IND_4828-WE-TPC_WRE
MCP73831: ESP32_WROVER_SPARKFUN-IC-POWER_MCP73831; ESP32_WROVER_SPARKFUN-IC-POWER_SOT23-5
PFMF.050.1: ESP32C6_VARISTORCN1812; ESP32C6_VARISTOR_CT/CN1812
Q1, Q2: 20V/4.2A/52mΩ/1.4W; ESP32_WROVER_SPARKFUN-DISCRETESEMI_SOT23-3
Q3: SI1308EDL-T1-GE3; SOT65P210X110-3N
R1, R1_PINH, R1_PINH1, R2-PINH1, R2_PINH, R4, R5, R6, R7, R8, R9, R10: 10K; ESP32_WROVER_EAGLE-LTSPICE_R0402
R1_BAT: 200; ESP32_WROVER_EAGLE-LTSPICE_R0402
R1_PWRUSB: 100K; ESP32_WROVER_EAGLE-LTSPICE_R0402
R2: 2.2; ESP32_WROVER_EAGLE-LTSPICE_R0402
R2-USB, R2-USB1: 5k1; ESP32_WROVER_EAGLE-LTSPICE_R0402
R2_BAT: 2K; ESP32_WROVER_EAGLE-LTSPICE_R0402
R3: 0.47; ESP32_WROVER_EAGLE-LTSPICE_R0402
RESET_BUTTON: BUTTON_CUSYOMV1; MYBUTTON
R_BOOT: 10K; ESP32_WROVER_EAGLE-LTSPICE_R0402
R_CAPACITOR: 15; ESP32_WROVER_EAGLE-LTSPICE_R0402
R_CHANGE: 10K; ESP32_WROVER_EAGLE-LTSPICE_R0402
R_CL1: 10K; ESP32_WROVER_EAGLE-LTSPICE_R0402
R_RESET: 10K; ESP32_WROVER_EAGLE-LTSPICE_R0402
SENSOR2: ESP32_WROVER_BME680_BME680; ESP32_WROVER_BME680_PSON80P300X300X100-8N
SJ1: &; SJ
TP1, TP2, TP3, TP4, TP5, TP6, TP7, TP8, TP9, TP10, TP11, TP12, TP13, TP14, TP15, TP16, TP17: TPTP20R; TP20R
U1: W25Q512JVEIQ; SON127P600X800X80-9N
U2: ESP32-C6-WROOM-1-N8; XCVR_ESP32-C6-WROOM-1-N8
U3: DS3231SN#; SOIC127P1032X265-16N
U4: MAX17048G+T10; SON50P200X200X80-9N

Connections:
3V3: C1_BAT2.1, C3.+, C9.1, D7.2 (ANODE), IC1.2 (VDD), IC4.5 (VOUT), J3.2, J4.P4 (VDD), Q2.3 (D), R1.1, R1_PINH1.2, R2-PINH1.1, R2-PINH1.2, R5.2, R6.2, R7.2, R8.2, R9.2, R10.2, R_BOOT.1, R_CHANGE.1, R_CL1.1, R_RESET.1, TP16.TP, U1.3 (!WP!(IO2)), U1.7 (!HOLD!/!RESET!(IO3)), U1.8 (VCC), U2.2 (3V3), U3.2 (VCC)
32KHZ: U2.9 (IO1), U3.1 (32KHZ)
DN: D1.4 (I/O2_2), J2.A7, J2.B7
DP: D1.6 (I/O1_2), J2.A6, J2.B6
EPD_3V3: C7.1, EPD_C5.1, J1.15, J1.16, L1.2, Q2.2 (S), TP17.TP
EPD_3V3_C: Q2.1 (G), R_CL1.2, TP13.TP, U2.18 (IO20)
EPD_BUSY: J1.9, TP9.TP, U2.26 (IO3)
EPD_CS: D6.2, J1.12, R9.1, TP10.TP, U2.11 (IO10)
EPD_DC: J1.11, TP11.TP, U2.5 (IO5)
EPD_RST: J1.10, TP12.TP, U2.21 (IO23)
FLASH_CS: D9.2, R5.1, U1.1 (!CS), U2.12 (IO11)
GDR: J1.2, Q3.1 (G), R4.1
GND: BOOT_BUTTON.1, BOOT_BUTTON.2, C1.2, C1_BAT.2, C1_BAT1.2, C1_BAT2.2, C2.2, C2_BAT.2, C3.-, C4_USB.2, C5.2, C5_USB.2, C6.2, C7.2, C8.2, C9.2, C10.2, C10_SUPERCAP.1, CHANGE_BUTTON.1, CHANGE_BUTTON.2, C_DELAY.2, D1.2 (GND), D3.1 (K), D6.1, D8.1, D9.1, D10.1, D11.1, D12.1, EPD_C1.2, EPD_C2.2, EPD_C5.2, EPD_C6.2, EPD_C7.2, EPD_C8.2, EPD_C9.2, EPD_C10.2, EPD_C11.2, EPD_C12.2, IC1.3 (GND), IC4.2 (VSS), J1.8, J1.17, J1.MP1, J1.MP2, J2.A1, J2.A12, J2.B1, J2.B12, J2.MP1, J2.MP2, J2.MP3, J2.MP4, J3.1, J4.G1 (GND_1), J4.G2 (GND_2), J4.G3 (GND_3), J4.G4 (GND_4), J4.P6 (VSS), MCP73831.2 (VSS), R1_PWRUSB.1, R2.1, R2-USB.2, R2-USB1.1, R2_BAT.1, R4.2, RESET_BUTTON.1, RESET_BUTTON.2, SENSOR2.1 (GND), SENSOR2.5 (SDO), SENSOR2.7 (GND), SJ1.1, TP4.TP, TP5.TP, U1.4 (GND), U1.9 (EXP), U2.1 (GND), U2.28 (GND), U2.29_1 (GND), U2.29_2 (GND), U2.29_3 (GND), U2.29_4 (GND), U2.29_5 (GND), U2.29_6 (GND), U2.29_7 (GND), U2.29_8 (GND), U2.29_9 (GND), U3.13 (GND), U4.1 (CTG), U4.4 (GND), U4.6 (QSTRT), U4.9 (EP)
GPIO8: R1.2, U2.10 (IO8)
I2C_PW: C1.1, C2.1, R1_PINH.2, R2_PINH.2, SENSOR2.2 (CSB), SENSOR2.6 (VDDIO), SENSOR2.8 (VDD), U2.17 (IO19)
INT_RTC: R1_PINH1.1, TP15.TP, U2.8 (IO0), U3.3 (SQW/!INT)
IO/BOOT: BOOT_BUTTON.3, BOOT_BUTTON.4, C6.1, R_BOOT.2, U2.15 (IO9)
IO/CHANGE: C10.1, CHANGE_BUTTON.3, CHANGE_BUTTON.4, R_CHANGE.2, U2.23 (IO15)
MISO: D12.2, J4.P7 (DAT0), R8.1, TP6.TP, U1.2 (DO(IO1)), U2.27 (IO2)
MOSI: D11.2, J1.14, J4.P3 (CMD), R7.1, TP7.TP, U1.5 (DI(IO0)), U2.7 (IO7)
unnamed: J2.A5, R2-USB1.2
unnamed: J2.B5, R2-USB.1
unnamed: C1_BAT1.1, D2.1 (CATHODE), IC4.1 (VIN), IC4.3 (CE), Q1.2 (S)
unnamed: MCP73831.1 (STAT), R1_BAT.1
unnamed: C4.1, D3.2 (A), D4.1 (K)
unnamed: CHG_LED.C, R1_BAT.2
unnamed: MCP73831.5 (PROG), R2_BAT.2
unnamed: EPD_C2.1, J1.5
unnamed: EPD_C1.1, J1.4
unnamed: C_DELAY.1, IC1.5 (CT)
unnamed: D7.1 (CATHODE), R_CAPACITOR.2
unnamed: EPD_C12.1, J1.24
unnamed: EPD_C10.1, J1.22
unnamed: EPD_C8.1, J1.20
unnamed: EPD_C6.1, J1.18
unnamed: EPD_C7.1, J1.19
PREVGH: D5.1 (K), EPD_C9.1, J1.21
PREVGL: D4.2 (A), EPD_C11.1, J1.23
RESE: J1.3, Q3.2 (S), R3.1
RESE': R2.2, R3.2, SJ1.2
RESET: C5.1, IC1.1 (VOUT), RESET_BUTTON.3, RESET_BUTTON.4, R_RESET.2, U2.3 (EN)
RTC_RST: U2.16 (IO18), U3.4 (!RST)
RX: TP2.TP, U2.24 (RXD0/GPIO17)
SCK: D10.2, J1.13, J4.P5 (CLK), R6.1, TP8.TP, U1.6 (CLK), U2.6 (IO6)
SCL: J3.4, R2_PINH.1, SENSOR2.4 (SCK), U2.20 (IO22), U3.16 (SCL), U4.7 (SCL)
SDA: J3.3, R1_PINH.1, SENSOR2.3 (SDI), U2.19 (IO21), U3.15 (SDA), U4.8 (SDA)
SRC: C4.2, D5.2 (A), L1.1, Q3.3 (D)
SS_SD: D8.2, J4.P2 (CD/DAT3), R10.1, U2.4 (IO4)
TX: TP1.TP, U2.25 (TXD0/GPIO16)
USB_D+: D1.1 (I/O1_1), U2.14 (IO13)
USB_D-: D1.3 (I/O2_1), U2.13 (IO12)
VBAT: C2_BAT.1, MCP73831.3 (VBAT), Q1.3 (D), TP3.TP, U4.2 (CELL), U4.3 (VDD)
VBUS: C1_BAT.1, C4_USB.1, C5_USB.1, CHG_LED.A, D1.5 (VBUS), D2.2 (ANODE), MCP73831.4 (VIN), PFMF.050.1.2, Q1.1 (G), R1_PWRUSB.2, TP14.TP
VRTC: C8.1, C10_SUPERCAP.2, R_CAPACITOR.1, U3.14 (VBAT)
VUSB: J2.A4, J2.A9, J2.B4, J2.B9, PFMF.050.1.1

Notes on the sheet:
68uH
USB C connector & ESD protection
LDO Voltage Regulator
SD Card
ESP32 C6
Li-Po Battery Charging Controller
E-Paper Drive Circuit
Display Type Selector
E-Paper Display Header
EPD Power
Environmental Sensor BME688
Voltage Supervisor + Reset & Boot / IO Button
Battery Charge Level
External NOR Flash 64MB
SPI ESD Protection Lines
Qwiic / Stemma QT
Test Pads
RTC Module DS3231SN
drawn by: Florean Sara-Denisa

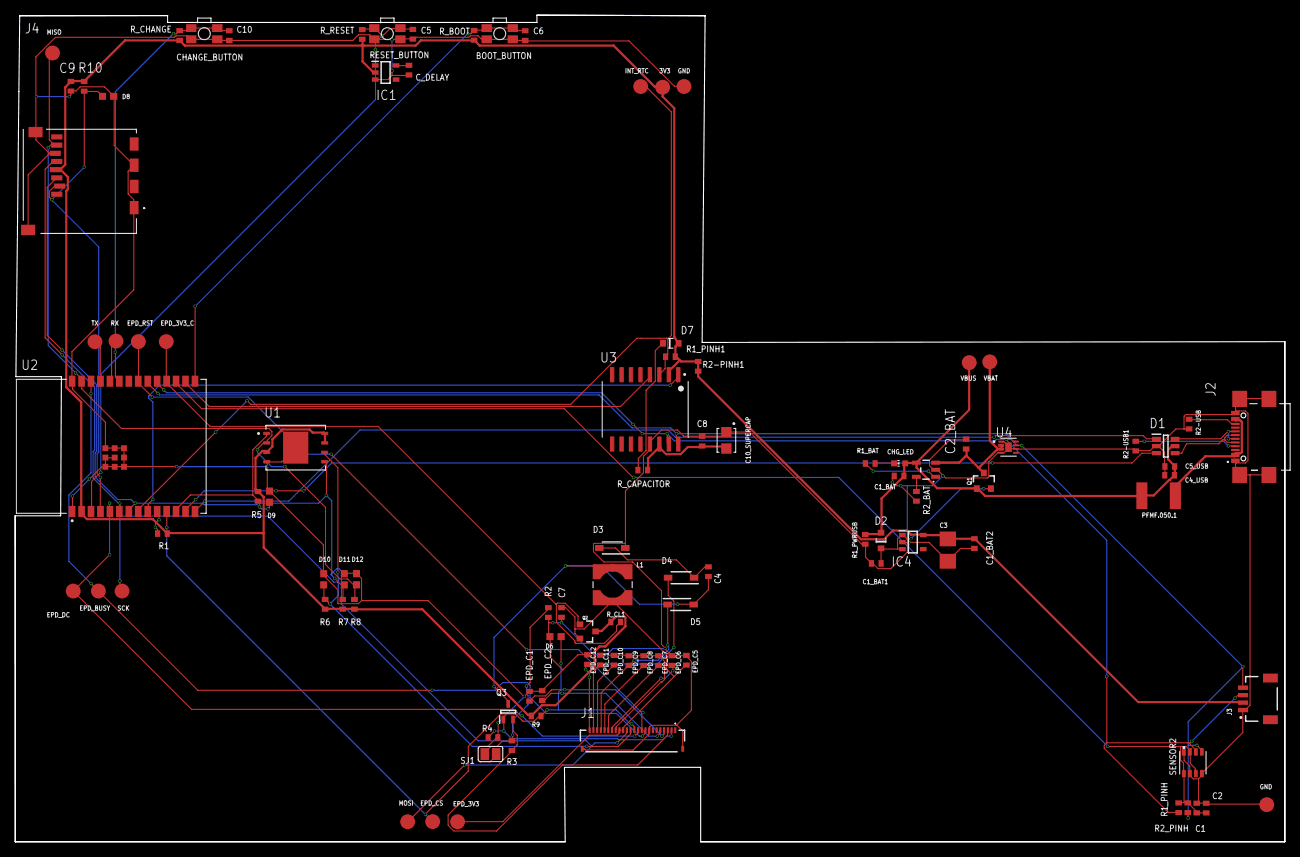
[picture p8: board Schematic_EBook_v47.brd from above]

Board: 2 copper layers, 170.6 x 111.1 mm, 103 parts (0 on the bottom side), 55 nets.

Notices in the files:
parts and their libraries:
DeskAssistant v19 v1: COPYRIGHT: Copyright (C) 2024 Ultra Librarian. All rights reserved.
